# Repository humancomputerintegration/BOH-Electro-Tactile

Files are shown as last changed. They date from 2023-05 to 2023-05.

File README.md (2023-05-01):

# Full-Hand Electro Tactile Feedback without Obstructing Palmar Side of Hand

This is the repository for PCB schematics and Arduino codes used for the "Full-Hand Electro Tactile Feedback without Obstructing Palmar Side of Hand" paper (ACM CHI2023).

For more information, please refer to our paper: http://lab.plopes.org/#boh-electro-tactile

## notes:
1.	For PCB, the design originally assumes the use of the Bluetooth Module + Lipo battery but also works with normal Serial + power via Seeeduino XIAO's USB-C. If you go for this tethered option, ensure the battery is not connected, the power switch on the PCB is toggled ON, and the Bluetooth module is removed.
2.	The Kicad project for the PCB has not been tested for library compatibility, so let us know if it does not appear properly on your end, but just uploading the Gerber file should suffice for ordering the PCB.
3.	The Arduino code is a generic program to drive the circuit in response to Serial messages from other program instances such as Unity, Python, Processing, etc.

# citing
When using or building upon this device in an academic publication, please consider citing as follows:

Yudai Tanaka, Alan Shen, Andy Kong, and Pedro Lopes. 2023. Full-Hand Electro-Tactile Feedback without Obstructing Palmar Side of Hand. In Proceedings of the 2023 CHI Conference on Human Factors in Computing Systems (CHI'23), April 23-28, 2023, Hamburg, Germany. ACM, NewYork, NY, USA, 15 pages. https://dl.acm.org/doi/abs/10.1145/3544548.3581382

# contact
For any questions about this repository, please contact yudaitanaka@uchicago.edu

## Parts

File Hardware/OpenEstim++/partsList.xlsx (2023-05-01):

Comment | Designator
3.7 V Lipo Battery | J1
U1V11F5 (3.7V/5V converter) | J1
HC-06 (bluetooth module) | J3
NMT0572SC (5V/72V converter) | U1
HV2701 | U3
Seeeduino XIAO | U4
LMV358 (op amp) | U5
FCX705 (transistor) | U6, U8
BSS87 (FET) | U7
E-452 (current limiting diode) | D2
TL2230OAF140 (switch) | SW1

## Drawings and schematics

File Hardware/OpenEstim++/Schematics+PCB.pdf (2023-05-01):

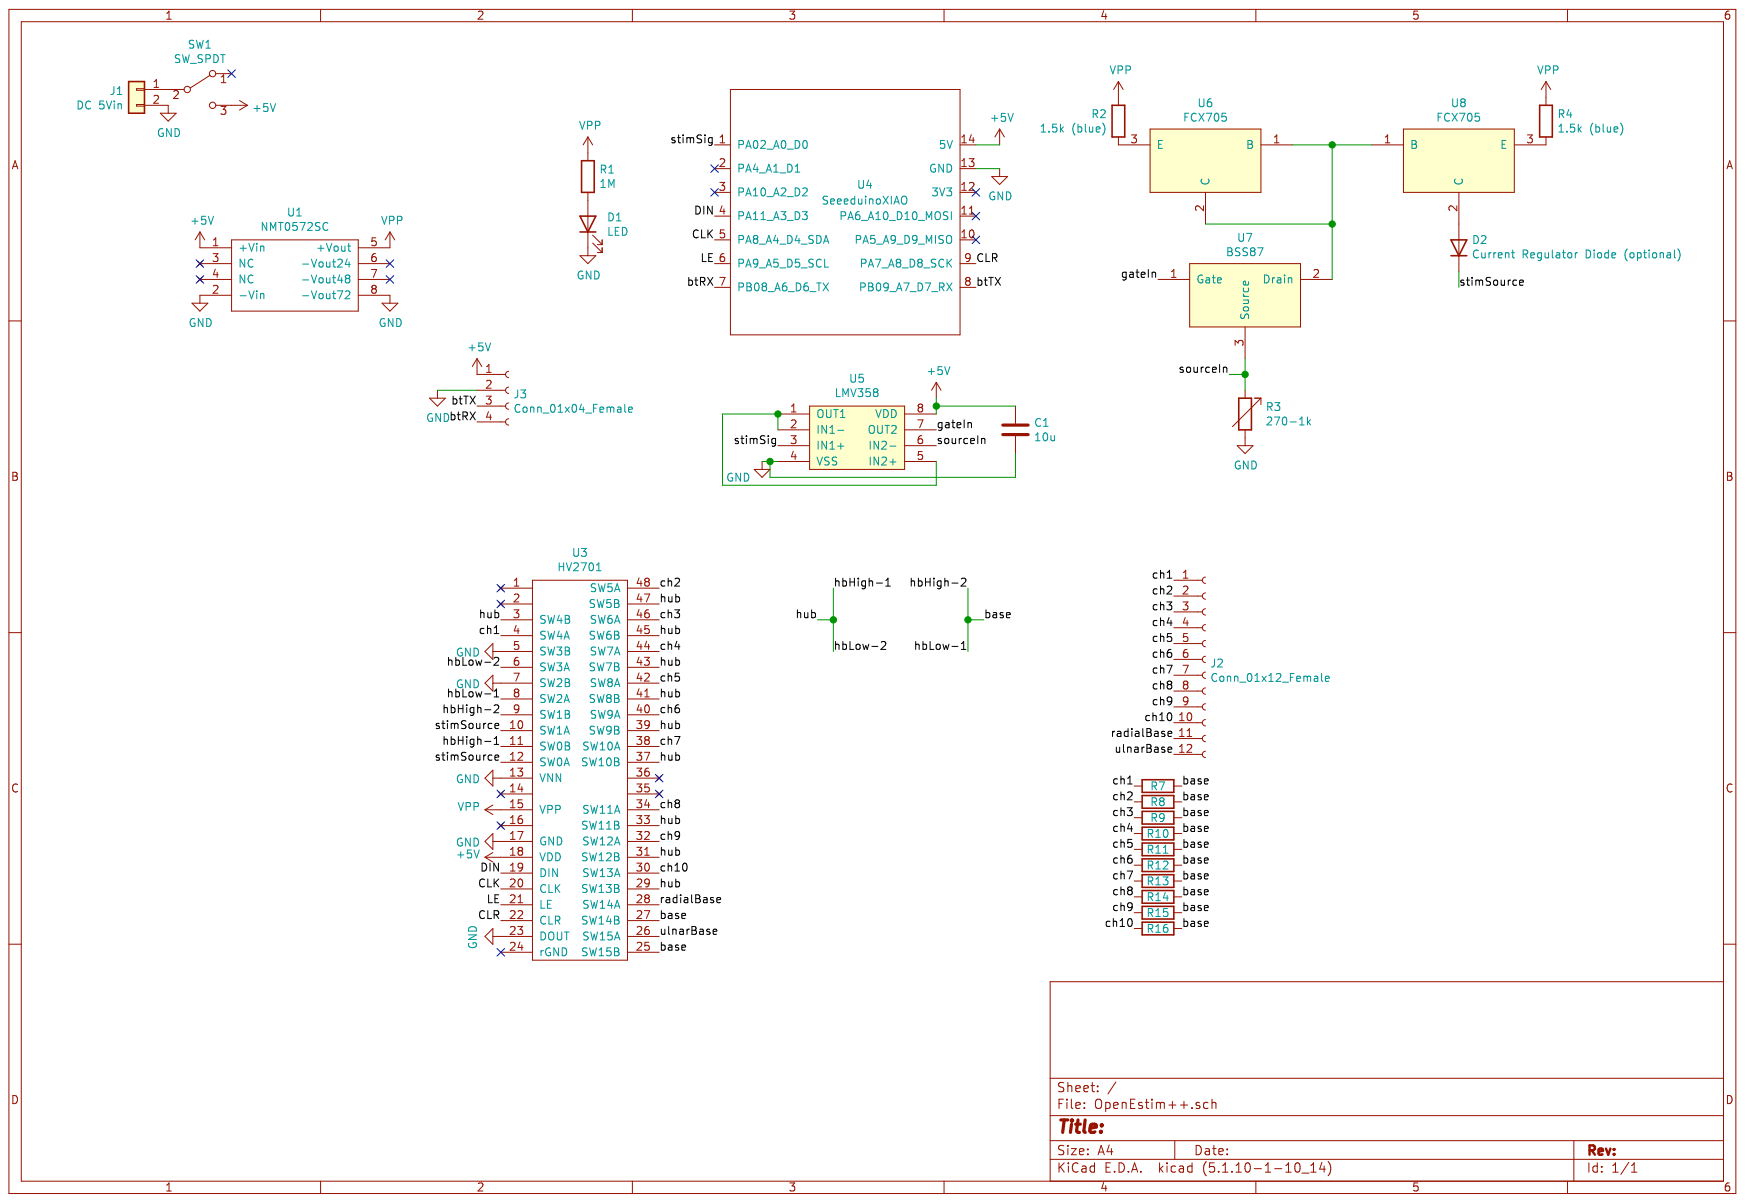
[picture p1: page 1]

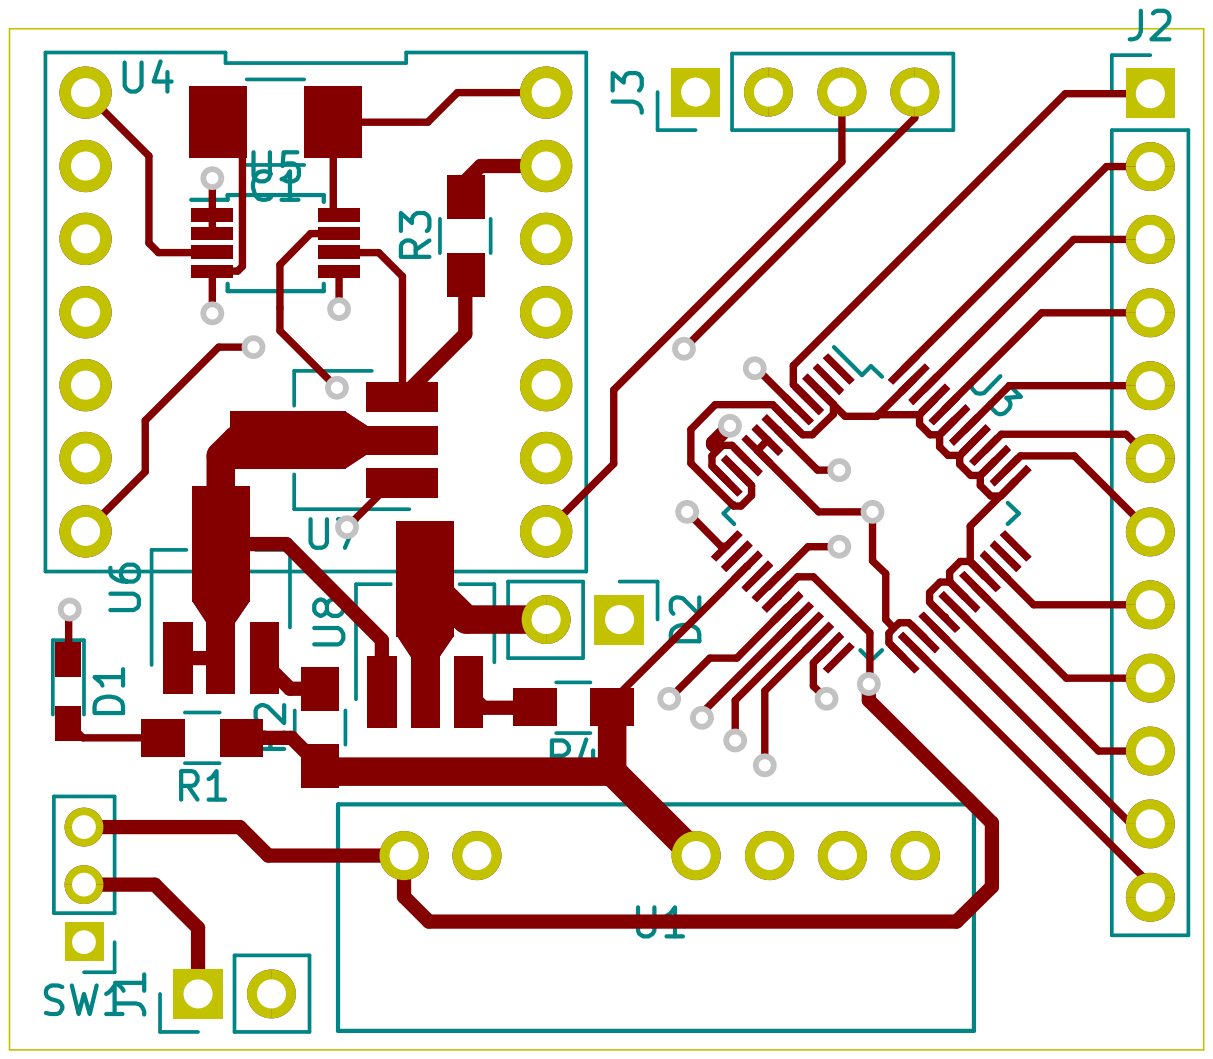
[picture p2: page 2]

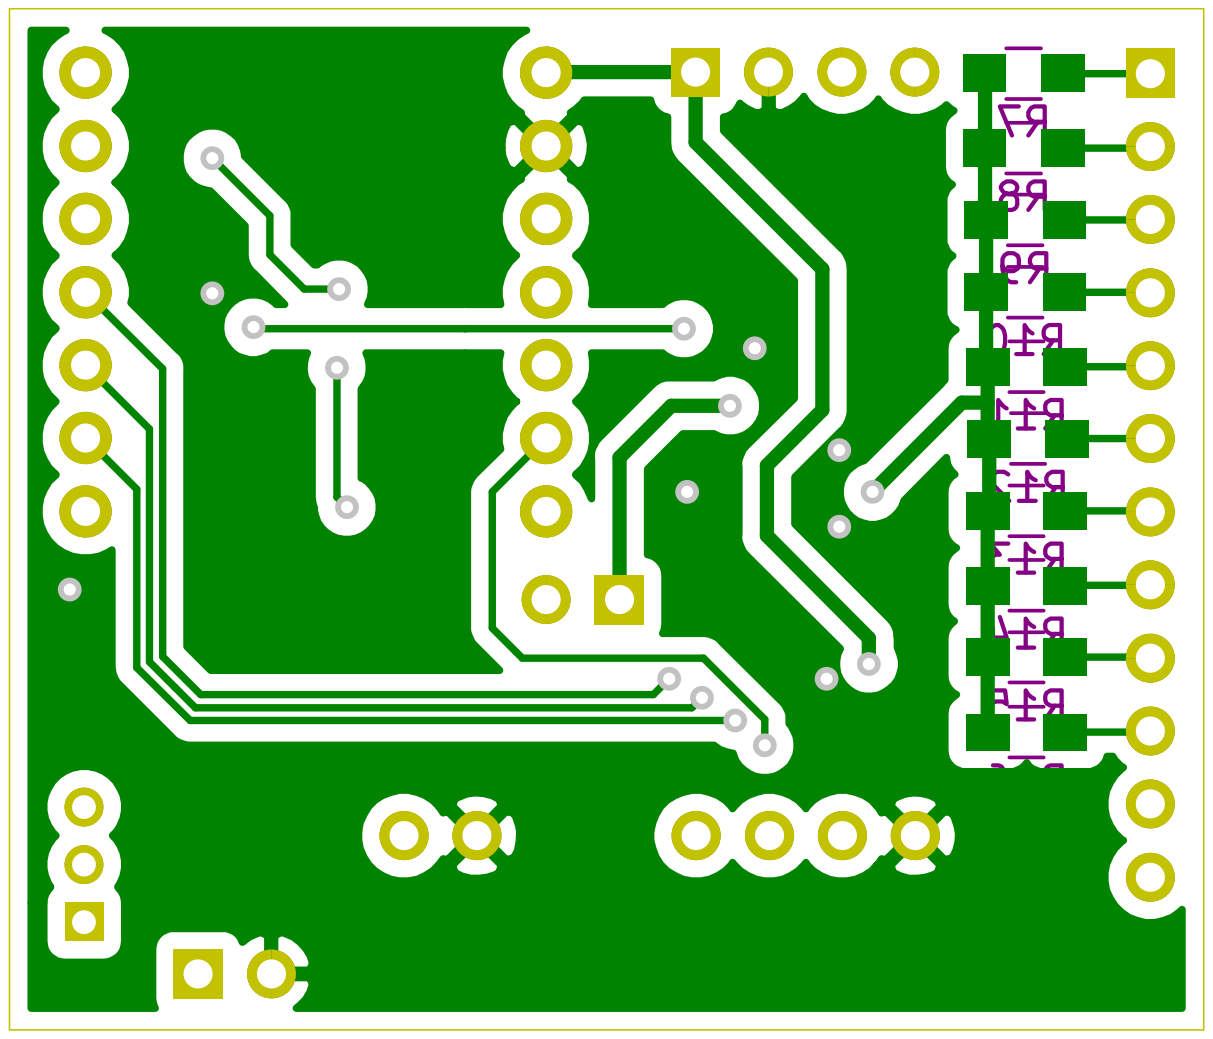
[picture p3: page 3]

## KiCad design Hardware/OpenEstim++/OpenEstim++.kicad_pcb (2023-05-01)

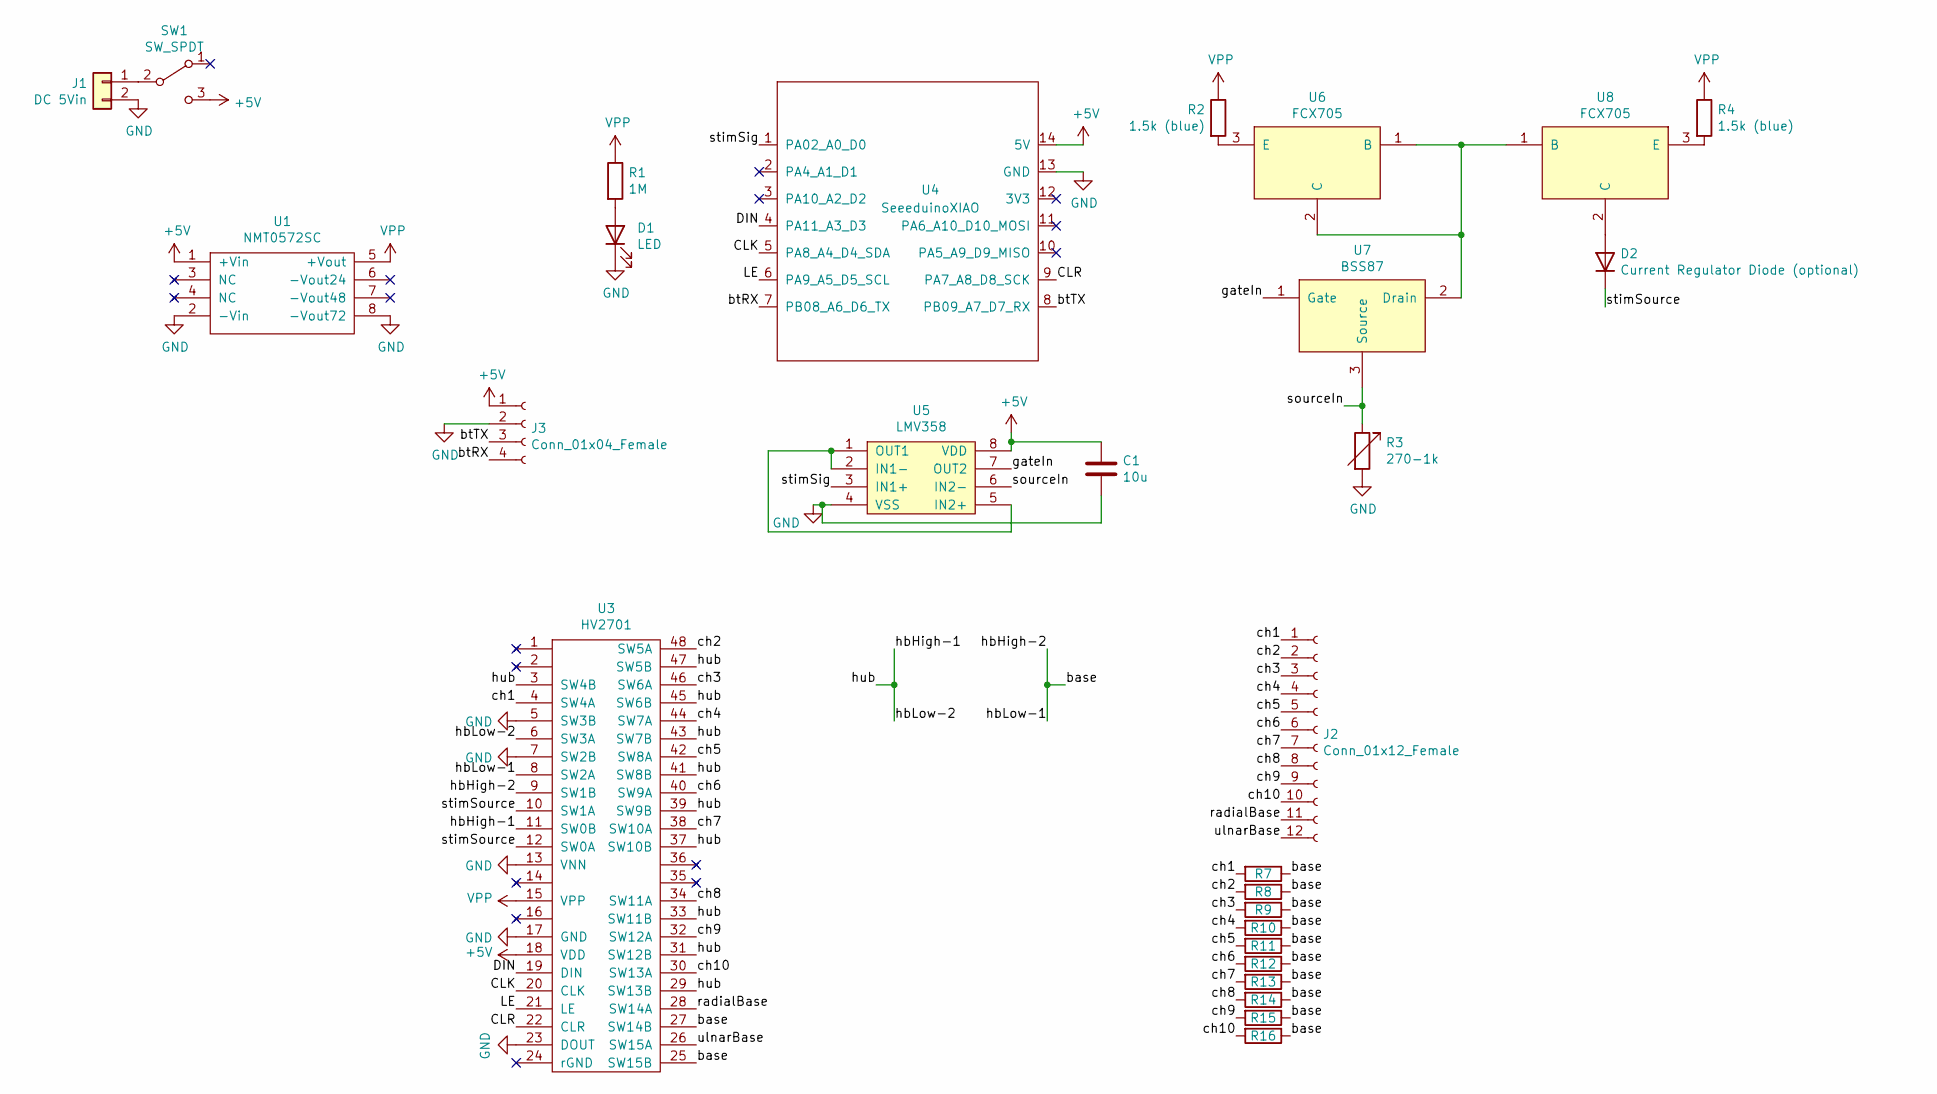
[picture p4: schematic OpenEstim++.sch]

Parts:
C1: 10u; C_1210_HandSoldering
D1: LED; LED_0603_HandSoldering
D2: Current Regulator Diode (optional); Pin_Header_Straight_1x02_Pitch2.54mm
J1: DC 5Vin; Pin_Header_Straight_1x02_Pitch2.54mm
J2: Conn_01x12_Female; Pin_Header_Straight_1x12_Pitch2.54mm
J3: Conn_01x04_Female; Pin_Header_Straight_1x04_Pitch2.54mm
R1: 1M; R_0805_HandSoldering
R2, R4: 1.5k (blue); R_0805_HandSoldering
R3: 270-1k; R_0805_HandSoldering
R7, R8, R9, R10, R11, R12, R13, R14, R15, R16: R; R_0805_HandSoldering
SW1: SW_SPDT; Pin_Header_Straight_1x03_Pitch2.00mm
U1: NMT0572SC
U3: HV2701; LQFP-48_7x7mm_Pitch0.5mm
U4: SeeeduinoXIAO; seeeduinoXiao
U5: LMV358; MSOP-8_3x3mm_Pitch0.65mm
U6, U8: FCX705; SOT-89-3_Handsoldering
U7: BSS87; SOT-89-3_Handsoldering

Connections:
+5V: C1.1, J3.1, SW1.3 (C), U1.1 (+Vin), U3.18 (VDD), U4.14 (5V), U5.8 (VDD)
/CLK: U3.20 (CLK), U4.5 (PA8_A4_D4_SDA)
/CLR: U3.22 (CLR), U4.9 (PA7_A8_D8_SCK)
/DIN: U3.19 (DIN), U4.4 (PA11_A3_D3)
/LE: U3.21 (LE), U4.6 (PA9_A5_D5_SCL)
/base: R7.1, R8.1, R9.1, R10.1, R11.1, R12.1, R13.1, R14.1, R15.1, R16.1, U3.8 (SW2A), U3.9 (SW1B), U3.25 (SW15B), U3.27 (SW14B)
/btRX: J3.4, U4.7 (PB08_A6_D6_TX)
/btTX: J3.3, U4.8 (PB09_A7_D7_RX)
/ch1: J2.1, R7.2, U3.4 (SW4A)
/ch2: J2.2, R8.2, U3.48 (SW5A)
/ch3: J2.3, R9.2, U3.46 (SW6A)
/ch4: J2.4, R10.2, U3.44 (SW7A)
/ch5: J2.5, R11.2, U3.42 (SW8A)
/ch6: J2.6, R12.2, U3.40 (SW9A)
/ch7: J2.7, R13.2, U3.38 (SW10A)
/ch8: J2.8, R14.2, U3.34 (SW11A)
/ch9: J2.9, R15.2, U3.32 (SW12A)
/ch10: J2.10, R16.2, U3.30 (SW13A)
/gateIn: U5.7 (OUT2), U7.1 (Gate)
/hbHigh-1: U3.3 (SW4B), U3.6 (SW3A), U3.11 (SW0B), U3.29 (SW13B), U3.31 (SW12B), U3.33 (SW11B), U3.37 (SW10B), U3.39 (SW9B), U3.41 (SW8B), U3.43 (SW7B), U3.45 (SW6B), U3.47 (SW5B)
/radialBase: J2.11, U3.28 (SW14A)
/sourceIn: R3.1, U5.6 (IN2-), U7.3 (Source)
/stimSig: U4.1 (PA02_A0_D0), U5.3 (IN1+)
/stimSource: D2.1 (K), U3.10 (SW1A), U3.12 (SW0A)
/ulnarBase: J2.12, U3.26 (SW15A)
GND: C1.2, D1.1 (K), J1.2, J3.2, R3.2, U1.2 (-Vin), U1.8 (-Vout72), U3.5 (SW3B), U3.7 (SW2B), U3.13 (VNN), U3.17 (GND), U3.23 (DOUT), U4.13 (GND), U5.4 (VSS)
unnamed: D1.2 (A), R1.2
unnamed: D2.2 (A), U8.2 (C)
unnamed: J1.1, SW1.2 (B)
unnamed: R2.2, U6.3 (E)
unnamed: R4.2, U8.3 (E)
unnamed: U5.1 (OUT1), U5.2 (IN1-), U5.5 (IN2+)
unnamed: U6.1 (B), U6.2 (C), U7.2 (Drain), U8.1 (B)
VPP: R1.1, R2.1, R4.1, U1.5 (+Vout), U3.15 (VPP)

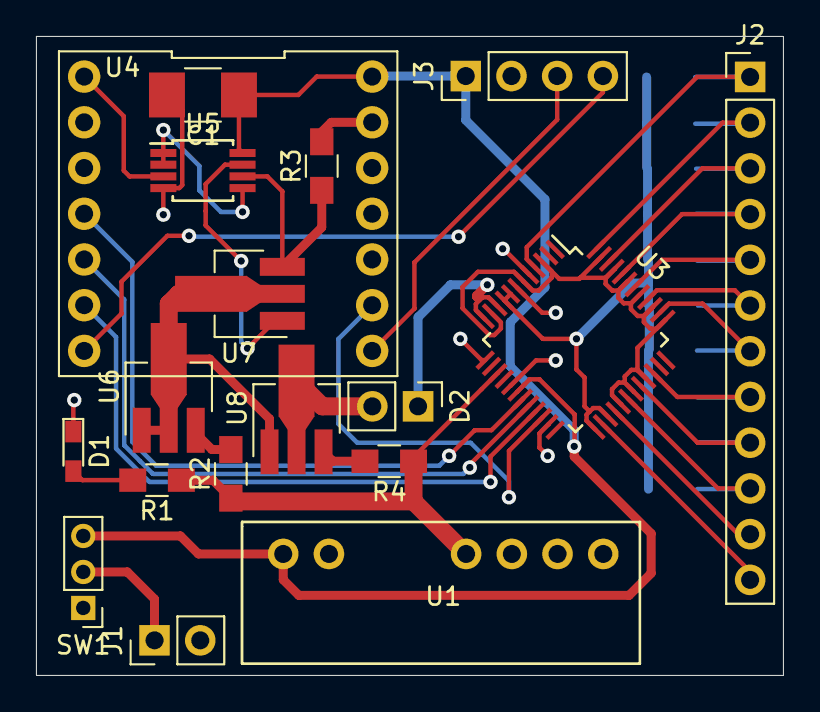
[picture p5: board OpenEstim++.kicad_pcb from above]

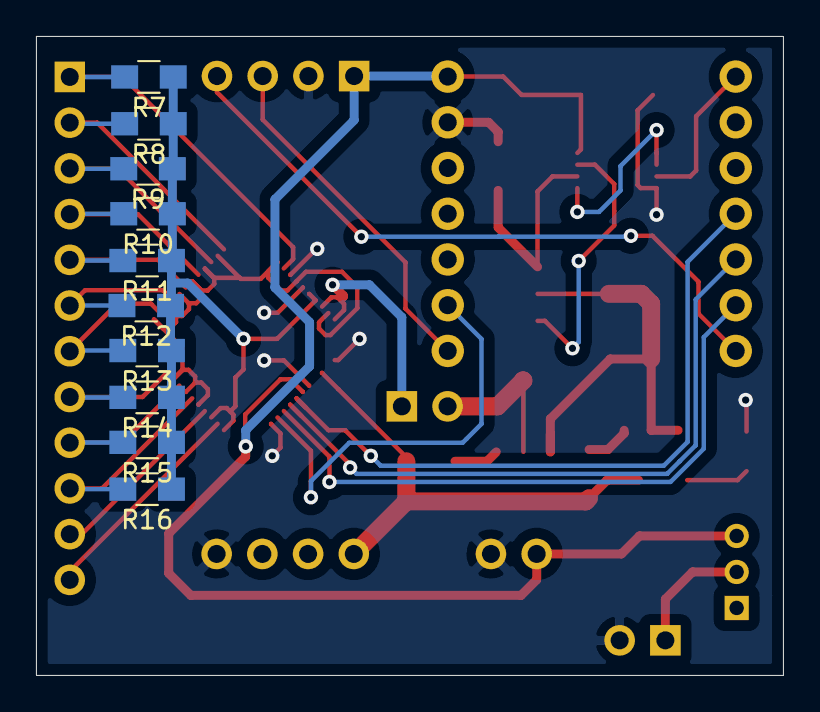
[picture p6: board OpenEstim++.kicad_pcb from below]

Board: 2 copper layers, 41.5 x 35.5 mm, 28 parts (10 on the bottom side), 34 nets.

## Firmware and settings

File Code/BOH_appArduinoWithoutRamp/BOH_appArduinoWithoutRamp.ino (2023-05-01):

#define outSerial Serial //normal: Serial; BlueTooth: Serial1

//#define SCLK 18
//#define MOSI 23
//#define MISO 19
//#define DA_CS 22
//#define AD_CS 5

#define DIN 3
#define CLK 4
#define LE 5
#define CLR 8

String mess1, mess2, mess3;
String channelIn[20];
String strengthIn[20];

float strength[20];

float smoothFactor = 0.2;
float smoothIncrement[20];
float curStrength[20] = {0,0,0,0,0,0,0,0,0,0,0,0,0,0,0,0,0,0,0,0};

int pulseWidth;
int frequency;
float invFrequency = 0;
int lastLoopStartTime = 0;

int trigger = 0;
int channel[20];

byte input[21][16] = {
  { 0,0,0,0,0,0,0,0,0,0,0,0,0,0,0,0 }, //initial
  { 0,1,0,0,0,0,0,0,0,0,0,1,0,1,0,1 }, //1 thumb
  { 0,1,0,0,0,0,0,0,0,0,0,1,1,0,1,0 }, //2 thumb
  { 0,1,0,0,0,0,0,0,0,0,1,0,0,1,0,1 }, //3 index_top
  { 0,1,0,0,0,0,0,0,0,0,1,0,1,0,1,0 }, //4 index_top
  { 0,1,0,0,0,0,0,0,0,1,0,0,0,1,0,1 }, //5 middle_top
  { 0,1,0,0,0,0,0,0,0,1,0,0,1,0,1,0 }, //6 middle_top
  { 1,0,0,0,0,0,0,0,1,0,0,0,0,1,0,1 }, //7 ring_top
  { 1,0,0,0,0,0,0,0,1,0,0,0,1,0,1,0 }, //8 ring_top
  { 1,0,0,0,0,0,0,1,0,0,0,0,0,1,0,1 }, //9 pinky_top
  { 1,0,0,0,0,0,0,1,0,0,0,0,1,0,1,0 }, //10 pinky_top
  { 0,1,0,0,0,0,1,0,0,0,0,0,0,1,0,1 }, //11 index_bottom
  { 0,1,0,0,0,0,1,0,0,0,0,0,1,0,1,0 }, //12 index_bottom
  { 0,1,0,0,0,1,0,0,0,0,0,0,0,1,0,1 }, //13 middle_bottom
  { 0,1,0,0,0,1,0,0,0,0,0,0,1,0,1,0 }, //14 middle_bottom
  { 1,0,0,0,1,0,0,0,0,0,0,0,0,1,0,1 }, //15 ring_bottom
  { 1,0,0,0,1,0,0,0,0,0,0,0,1,0,1,0 }, //16 ring_bottom
  { 1,0,0,1,0,0,0,0,0,0,0,0,0,1,0,1 }, //17 pinky_bottom
  { 1,0,0,1,0,0,0,0,0,0,0,0,1,0,1,0 }, //18 pinky_bottom
  { 1,1,1,0,0,0,0,0,0,0,0,0,0,1,0,1 }, //19 palm
  { 1,1,1,0,0,0,0,0,0,0,0,0,1,0,1,0 }  //20 palm
};

void setup() {
//  pinMode(DA_CS, OUTPUT);
//  pinMode(AD_CS, OUTPUT);
  pinMode( DIN, OUTPUT );
  pinMode( CLK, OUTPUT );
  pinMode( LE, OUTPUT );
  pinMode( CLR, OUTPUT );

//  SPI.begin(SCLK, MISO, MOSI);
//  SPI.setFrequency(32000000);
//  SPI.setDataMode(SPI_MODE0);
  outSerial.begin(115200);
  while (!outSerial);
  outSerial.setTimeout(15);
   
  digitalWrite(LE, HIGH);
  digitalWrite(CLR, LOW);
}

void loop() { 
  if (millis() < lastLoopStartTime + invFrequency*1000) return; //maintaining stimulation loop operates at the frequency.
  lastLoopStartTime = millis();


  if ( outSerial.available() ) {
    mess1 = outSerial.readStringUntil(',');
    mess2 = outSerial.readStringUntil(',');
    mess3 = outSerial.readStringUntil(',');

    for ( int i=0; i<20; i++ ) {
      strengthIn[i] = outSerial.readStringUntil(',');
      strength[i] = strengthIn[i].toInt();
      if (strength[i] > 1024) strength[i] = 1024;

      smoothIncrement[i] = abs(strength[i])*smoothFactor;
    } 
    
    for ( int i=0; i<20; i++ ) {
      if (i == 19) channelIn[i] = outSerial.readStringUntil('\n');
      else channelIn[i] = outSerial.readStringUntil(',');

      channel[i] = channelIn[i].toInt();
      if (!channel[i])
      {
        curStrength[i] = 0;
      }
    }

    pulseWidth = mess1.toInt();
    frequency = mess2.toInt();
    trigger = mess3.toInt();
        
    invFrequency = 1.0/frequency;
  } else {
    //outSerial.end();
  }
//  else {
//    trigger = 0;
//  }

  if (trigger == 1) {
    for ( int i=0; i<20; i++ ) {
      if (channel[i] == 1) {
      stim(i+1);
      }
      else delayMicroseconds(pulseWidth);
    }
  } 
  else if (trigger == 2) {
    pulseWidth = 50000;
    for ( int i=0; i<20; i++ ) {
      if (channel[i] == 1) {
      stim(i+1);
    }
}
  }
  else {
    //curStrength = 0;
    //digitalWrite(DA_CS, LOW);     //enable clock
    analogWrite(A0, 0); //SPI.transfer16(char(0) << 6);
    //digitalWrite(DA_CS, HIGH);
  }

//  if (pulseWidth == 0){
//    outSerial.end();
//    outSerial.begin(115200);
//    while (!outSerial);
//    outSerial.setTimeout(15);
//   
//    digitalWrite(LE, HIGH);
//    digitalWrite(CLR, LOW);
//  }
  
}

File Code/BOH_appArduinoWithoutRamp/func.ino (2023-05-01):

void stim(int j) {
    for ( int i=0; i<16; i++ ) {
      digitalWrite(CLK, LOW);
      delayMicroseconds(1);
      if (input[j][i] == 1) digitalWrite(DIN, HIGH);
      else digitalWrite(DIN, LOW);
      delayMicroseconds(1);
      digitalWrite(CLK, HIGH);
      delayMicroseconds(1);
    }
    digitalWrite(LE, LOW);
    delayMicroseconds(5);
    digitalWrite(DIN, LOW);
    delayMicroseconds(5);
    digitalWrite(CLK, LOW);
    delayMicroseconds(10);

    curStrength[j-1] = strength[j-1];
    
//    digitalWrite(DA_CS, LOW);     //enable clock
//    SPI.transfer16(char(curStrength[j-1]) << 6);
//    digitalWrite(DA_CS, HIGH);

    analogWrite(A0, curStrength[j-1]);
    
    delayMicroseconds(pulseWidth);
    
//    digitalWrite(DA_CS, LOW);     //enable clock
//    SPI.transfer16(0 << 6);
//    digitalWrite(DA_CS, HIGH);

    analogWrite(A0, 0);
    
    delayMicroseconds(10);
    digitalWrite(LE, HIGH);
    //delayMicroseconds(20);
}
